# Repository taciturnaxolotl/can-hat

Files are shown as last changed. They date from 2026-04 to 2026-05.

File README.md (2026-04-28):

# CANopy

the main schematic
the branch schematic

The canonical repo for this is hosted on tangled over at [`dunkirk.sh/CANopy`](https://tangled.org/dunkirk.sh/CANopy)

## BOM

| Name | Purpose | Quantity | Total Cost (USD) | Distributor |
|---|---|---|---|---|
| [2×20 40-pin stacking female header](https://www.amazon.com/dp/B0827THC7R) | 15-16mm pin length to clear Pi 5 active cooler, hand solder | 1 | $9.90 | Amazon |
| [10kΩ 0603](https://www.lcsc.com/product-detail/C25803.html) | MCP2518FD RESET pull-up and MCP2562FD STBY pull-down, PCBA | 100 | $0.18 | LCSC |
| [1kΩ 0603](https://www.lcsc.com/product-detail/C21190.html) | EEPROM write-protect pull-up to 3.3V, PCBA | 100 | $0.16 | LCSC |
| [3.9kΩ 0603](https://www.lcsc.com/product-detail/C23196.html) | EEPROM SDA/SCL pull-ups to 3.3V, PCBA | 100 | $0.16 | LCSC |
| [120Ω 0603](https://www.lcsc.com/product-detail/C25879.html) | CAN bus termination resistors, one per channel, PCBA | 100 | $0.09 | LCSC |
| [10µF 0805](https://www.lcsc.com/product-detail/C15850.html) | Bulk caps for 3.3V and 5V rails, PCBA | 20 | $0.43 | LCSC |
| [1µF 0603 X5R](https://www.lcsc.com/product-detail/C15849.html) | Decoupling caps for all ICs, PCBA | 100 | $0.56 | LCSC |
| [15EDGRC-3.5-02P (plug & header)](https://www.lcsc.com/product-detail/C5632692.html) | PCB-side right-angle pluggable terminal block, 3.5mm pitch, 2-pin, hand solder | 10 | $3.21 | LCSC |
| [AT24C32D-SSHM-T](https://www.lcsc.com/product-detail/C60583.html) | 32Kbit I2C EEPROM for HAT ID, SOIC-8, hand solder | 5 | $1.48 | LCSC |
| [OVETGLJANF-40MHZ](https://www.lcsc.com/product-detail/C295515.html) | 40MHz active oscillator, 3.3V, SMD5032-4P, hand solder | 11 | $6.14 | LCSC |
| [MCP2562FDT-E/SN](https://www.lcsc.com/product-detail/C511335.html) | CAN FD transceiver with VIO pin, SOIC-8, hand solder | 11 | $12.87 | LCSC |
| [MCP2518FDT-H/SL](https://www.lcsc.com/product-detail/C626759.html) | CAN FD SPI controller, SOIC-14, hand solder | 11 | $27.07 | LCSC |

For use with the SystemCore the RSL can be emulated via the following

```python
# pseudocode
gpio = /sys/class/gpio/gpioXX/value
while True:
  enabled = read("/sys/kernel/can_heartbeat/enabledro")
  gpio.write(enabled)
  # add blink pattern logic for disabled state
  sleep(0.05)
```

### todo

- [ ] add testpoints on i2c and can rx/tx 0.1" header
- [ ] add termination resister jumper (dip switch block)
- [ ] add rsl mosfet switching ground
- [ ] [5v 5a pololu](https://www.pololu.com/product/2851)
- [ ] new screw blocks [DEGSON DG500-5.08-02P-14-00A(H)](https://www.lcsc.com/product-detail/C691859.html)
- [ ] esd diodes on the gpio pins for rsl
- [ ] 120 ohm differential pairs for can

<p align="center">
    
</p>

<p align="center">
    <i><code>&copy; 2026-present <a href="https://dunkirk.sh">Kieran Klukas</a></code></i>
</p>

<p align="center">
    
</p>

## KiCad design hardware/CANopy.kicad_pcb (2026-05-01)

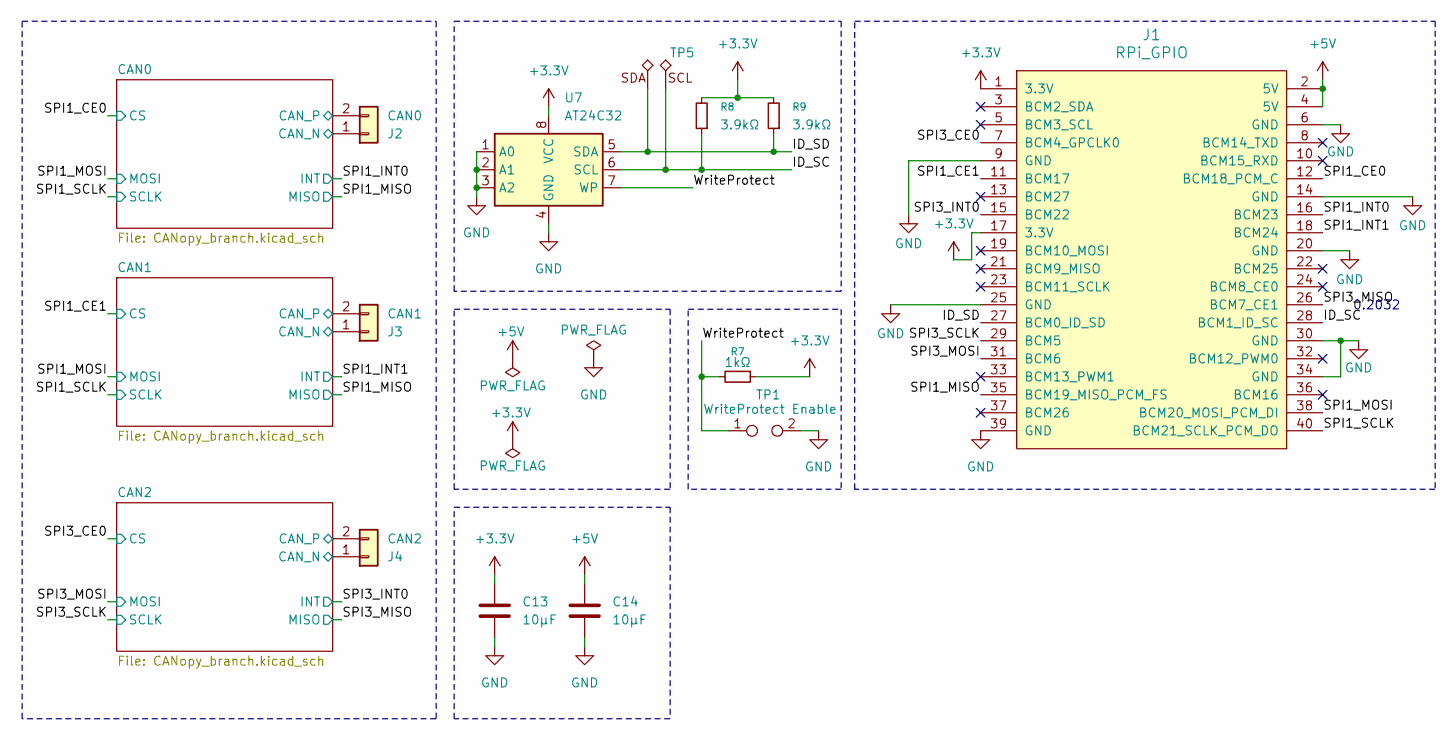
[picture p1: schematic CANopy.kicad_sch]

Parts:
C13, C14: 10µF; C_0805_2012Metric; LCSC C15850
J1: RPi_GPIO; RPI_Hat_B+
J2: CAN0; CONN-TH_DG500-5.08-02P-14-00A-H; LCSC C5632692
J3: CAN1; CONN-TH_DG500-5.08-02P-14-00A-H; LCSC C5632692
J4: CAN2; CONN-TH_DG500-5.08-02P-14-00A-H; LCSC C5632692
R7: 1kΩ; R_0603_1608Metric; LCSC C21190
R8, R9: 3.9kΩ; R_0603_1608Metric; LCSC C23196
TP1: WriteProtect Enable; TestPoint_2Pads_Pitch2.54mm_Drill0.8mm
TP5: SDA SCL
U7: AT24C32; SOIC-8_3.9x4.9mm_P1.27mm; LCSC C60583

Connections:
+3.3V: C13.1, J1.1 (3.3V), J1.17 (3.3V), R7.1, R8.2, R9.2, U7.8 (VCC); also elsewhere on the board
+5V: C14.1, J1.2 (5V), J1.4 (5V); also elsewhere on the board
/CAN0/CAN_N: J2.1; also elsewhere on the board
/CAN0/CAN_P: J2.2; also elsewhere on the board
/CAN1/CAN_N: J3.1; also elsewhere on the board
/CAN1/CAN_P: J3.2; also elsewhere on the board
/CAN2/CAN_N: J4.1; also elsewhere on the board
/CAN2/CAN_P: J4.2; also elsewhere on the board
/ID_SC: J1.28 (BCM1_ID_SC), R8.1, TP5.1, U7.6 (SCL)
/ID_SD: J1.27 (BCM0_ID_SD), R9.1, TP5.1, U7.5 (SDA)
/SPI1_CE0: J1.12 (BCM18_PCM_C); also elsewhere on the board
/SPI1_CE1: J1.11 (BCM17); also elsewhere on the board
/SPI1_INT0: J1.16 (BCM23); also elsewhere on the board
/SPI1_INT1: J1.18 (BCM24); also elsewhere on the board
/SPI1_MISO: J1.35 (BCM19_MISO_PCM_FS); also elsewhere on the board
/SPI1_MOSI: J1.38 (BCM20_MOSI_PCM_DI); also elsewhere on the board
/SPI1_SCLK: J1.40 (BCM21_SCLK_PCM_DO); also elsewhere on the board
/SPI3_CE0: J1.7 (BCM4_GPCLK0); also elsewhere on the board
/SPI3_INT0: J1.15 (BCM22); also elsewhere on the board
/SPI3_MISO: J1.26 (BCM7_CE1); also elsewhere on the board
/SPI3_MOSI: J1.31 (BCM6); also elsewhere on the board
/SPI3_SCLK: J1.29 (BCM5); also elsewhere on the board
/WriteProtect: R7.2, TP1.1, U7.7 (WP)
GND: C13.2, C14.2, J1.6 (GND), J1.9 (GND), J1.14 (GND), J1.20 (GND), J1.25 (GND), J1.30 (GND), J1.34 (GND), J1.39 (GND), TP1.2, U7.1 (A0), U7.2 (A1), U7.3 (A2), U7.4 (GND); also elsewhere on the board

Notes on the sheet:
0.2032

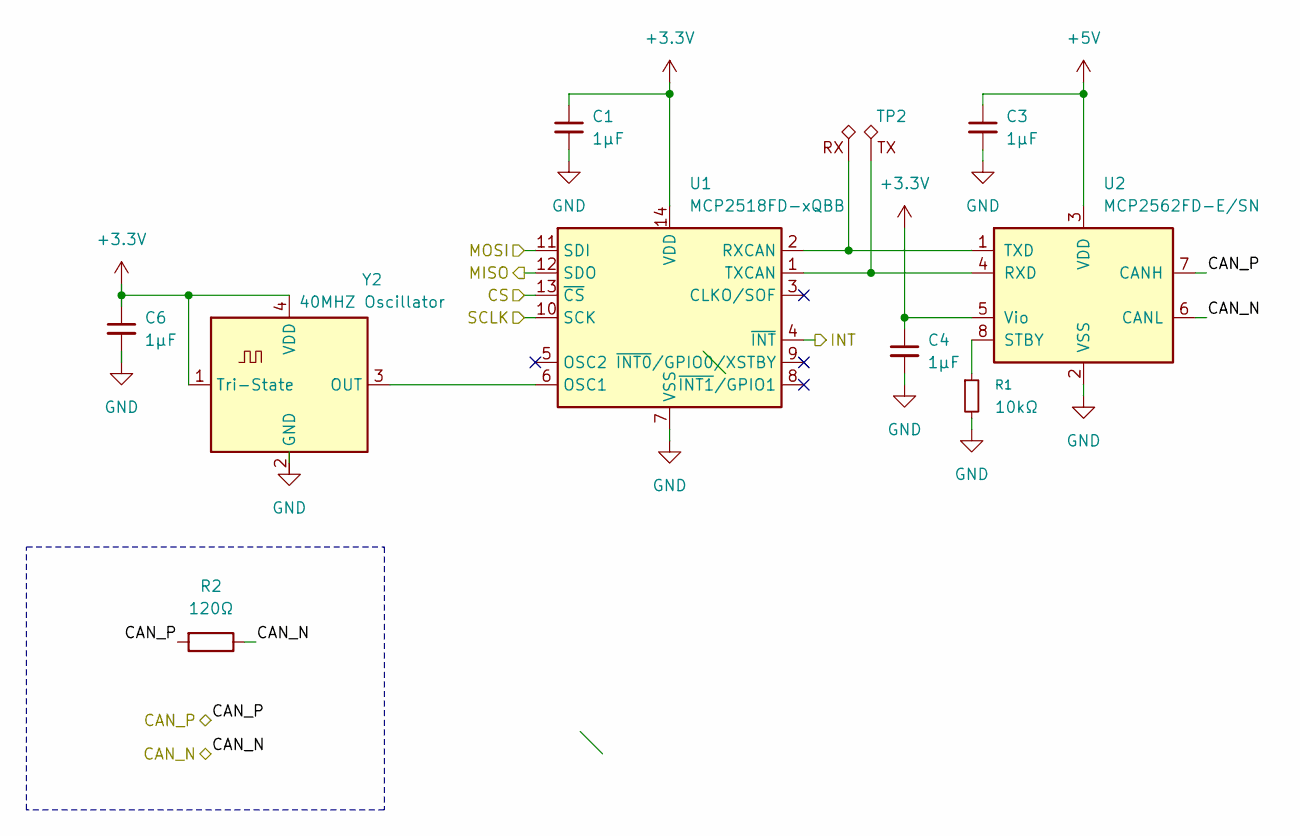
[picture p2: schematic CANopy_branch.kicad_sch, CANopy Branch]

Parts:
C1, C3, C4, C6: 1µF; C_0603_1608Metric; LCSC C14663
R1: 10kΩ; R_0603_1608Metric; LCSC C25803
R2: 120Ω; R_0603_1608Metric; LCSC C25879
TP2: CAN INTER RX TX
U1: MCP2518FD-xQBB; SOIC-14_L8.7-W3.9-P1.27-LS6.0-BL; LCSC C626759
U2: MCP2562FD-E/SN; SOIC-8_3.9x4.9mm_P1.27mm; LCSC C511335
Y2: 40MHZ Oscillator; Crystal_SMD_5032-4Pin_5.0x3.2mm; LCSC C295515

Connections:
+3.3V: C1.1, C4.1, C6.1, U1.14 (VDD), U2.5 (Vio), Y2.1 (Tri-State), Y2.4 (VDD); also elsewhere on the board
+5V: C3.1, U2.3 (VDD); also elsewhere on the board
/CAN0/CAN_N: R2.1, U2.6 (CANL); also elsewhere on the board
/CAN0/CAN_P: R2.2, U2.7 (CANH); also elsewhere on the board
/SPI1_CE0: U1.13 (~CS); also elsewhere on the board
/SPI1_INT0: U1.4 (~INT); also elsewhere on the board
/SPI1_MISO: U1.12 (SDO); also elsewhere on the board
/SPI1_MOSI: U1.11 (SDI); also elsewhere on the board
/SPI1_SCLK: U1.10 (SCK); also elsewhere on the board
GND: C1.2, C3.2, C4.2, C6.2, R1.2, U1.7 (VSS), U1.15 (VSS), U2.2 (VSS); also elsewhere on the board
unnamed: U1.2 (RXCAN), U2.1 (TXD)
unnamed: U1.1 (TXCAN), U2.4 (RXD)
unnamed: U1.6 (OSC1), Y2.3 (OUT)
unnamed: R1.1, U2.8 (STBY)

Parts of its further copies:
C2, C5, C7, C8, C9, C10, C11, C12: 1µF; C_0603_1608Metric; LCSC C14663
R3, R5: 120Ω; R_0603_1608Metric; LCSC C25879
R4, R6: 10kΩ; R_0603_1608Metric; LCSC C25803
U3, U5: MCP2518FD-xQBB; SOIC-14_L8.7-W3.9-P1.27-LS6.0-BL; LCSC C626759
U4, U6: MCP2562FD-E/SN; SOIC-8_3.9x4.9mm_P1.27mm; LCSC C511335
Y1, Y3: 40MHZ Oscillator; Crystal_SMD_5032-4Pin_5.0x3.2mm; LCSC C295515

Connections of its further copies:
+3.3V: C2.1, C5.1, C7.1, C9.1, C10.1, C11.1, U3.14 (VDD), U4.5 (Vio), U5.14 (VDD), U6.5 (Vio), Y1.1 (Tri-State), Y1.4 (VDD), Y3.1 (Tri-State), Y3.4 (VDD); also elsewhere on the board
+5V: C8.1, C12.1, U4.3 (VDD), U6.3 (VDD); also elsewhere on the board
/CAN1/CAN_N: R3.1, U4.6 (CANL); also elsewhere on the board
/CAN1/CAN_P: R3.2, U4.7 (CANH); also elsewhere on the board
/CAN2/CAN_N: R5.1, U6.6 (CANL); also elsewhere on the board
/CAN2/CAN_P: R5.2, U6.7 (CANH); also elsewhere on the board
/SPI1_CE1: U3.13 (~CS); also elsewhere on the board
/SPI1_INT1: U3.4 (~INT); also elsewhere on the board
/SPI1_MISO: U3.12 (SDO); also elsewhere on the board
/SPI1_MOSI: U3.11 (SDI); also elsewhere on the board
/SPI1_SCLK: U3.10 (SCK); also elsewhere on the board
/SPI3_CE0: U5.13 (~CS); also elsewhere on the board
/SPI3_INT0: U5.4 (~INT); also elsewhere on the board
/SPI3_MISO: U5.12 (SDO); also elsewhere on the board
/SPI3_MOSI: U5.11 (SDI); also elsewhere on the board
/SPI3_SCLK: U5.10 (SCK); also elsewhere on the board
GND: C2.2, C5.2, C7.2, C8.2, C9.2, C10.2, C11.2, C12.2, R4.2, R6.2, U3.7 (VSS), U4.2 (VSS), U5.7 (VSS), U6.2 (VSS); also elsewhere on the board
unnamed: U3.2 (RXCAN), U4.1 (TXD)
unnamed: U3.1 (TXCAN), U4.4 (RXD)
unnamed: U5.2 (RXCAN), U6.1 (TXD)
unnamed: U5.1 (TXCAN), U6.4 (RXD)
unnamed: U3.6 (OSC1), Y1.3 (OUT)
unnamed: R4.1, U4.8 (STBY)
unnamed: U5.6 (OSC1), Y3.3 (OUT)
unnamed: R6.1, U6.8 (STBY)

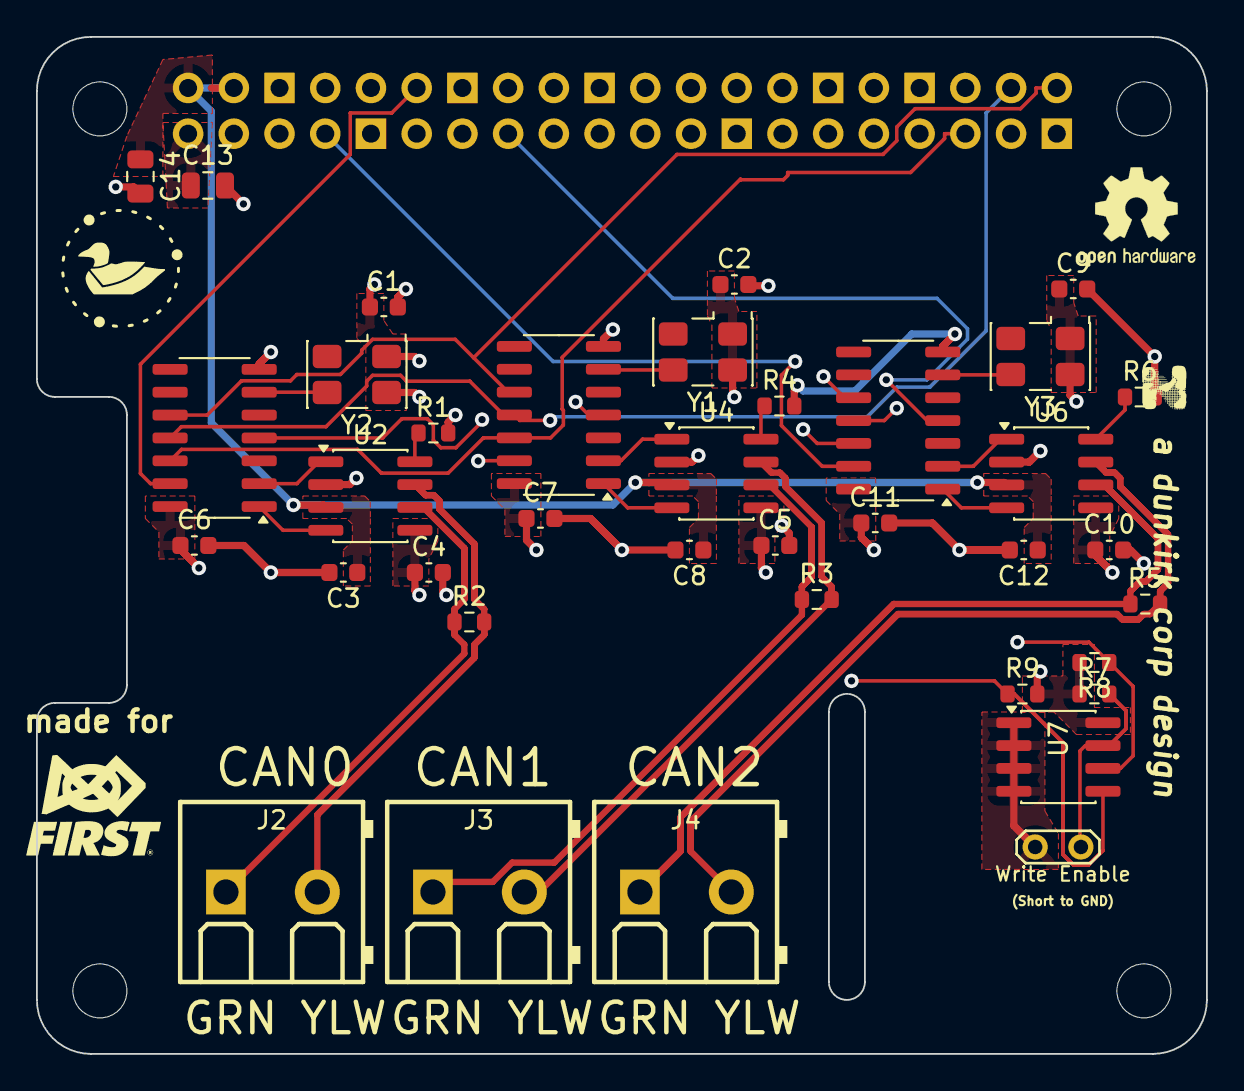
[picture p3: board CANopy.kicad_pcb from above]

Board: 4 copper layers, 65.0 x 56.5 mm, 41 parts (0 on the bottom side), 36 nets.

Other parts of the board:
duck-logo: LOGO
first-logo: LOGO
osh-hw: OSHW-Logo2_7.3x6mm_SilkScreen

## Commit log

2026-04-25 feat: init project
    [can-hat.kicad_pcb, can-hat.kicad_sch]
2026-04-25 feat: add can channels
    [can-hat.kicad_sch, can_channel.kicad_sch]
2026-04-26 feat: finish the schematic
    [can-hat.kicad_sch, can_channel.kicad_sch]
2026-04-26 feat: finish pcb
    [can-hat.kicad_pcb, can-hat.kicad_sch, can_channel.kicad_sch]
2026-04-26 chore: add parts and fix bom
    [can-hat.kicad_pcb, can-hat.kicad_sch, can_channel.kicad_sch]
2026-04-26 feat: rename to CANopy
    [CANopy.kicad_pcb, CANopy.kicad_sch, CANopy_branch.kicad_sch]
2026-04-27 feat: update schematic with proper cap sizes
    [CANopy.kicad_pcb, CANopy.kicad_sch, CANopy_branch.kicad_sch]
2026-05-01 feat: first pass reroute
    [CANopy.kicad_pcb, CANopy.kicad_sch, CANopy_branch.kicad_sch]
2026-05-01 feat: route 4 layer
    [CANopy.kicad_pcb, CANopy.kicad_sch]

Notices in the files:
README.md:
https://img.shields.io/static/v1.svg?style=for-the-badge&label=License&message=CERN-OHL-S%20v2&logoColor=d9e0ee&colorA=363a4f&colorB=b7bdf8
